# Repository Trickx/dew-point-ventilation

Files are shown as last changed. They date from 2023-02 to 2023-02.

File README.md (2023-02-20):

***

# Dew Point Ventilation

**Ventilation is the best and cheapest measure against damp cellars - at least if done right.
In this project, an ESP8266 (NodeMCU) monitors dew points from the inside and outside and activates up to 4 fans to transport the moisture in the air to the outside.**

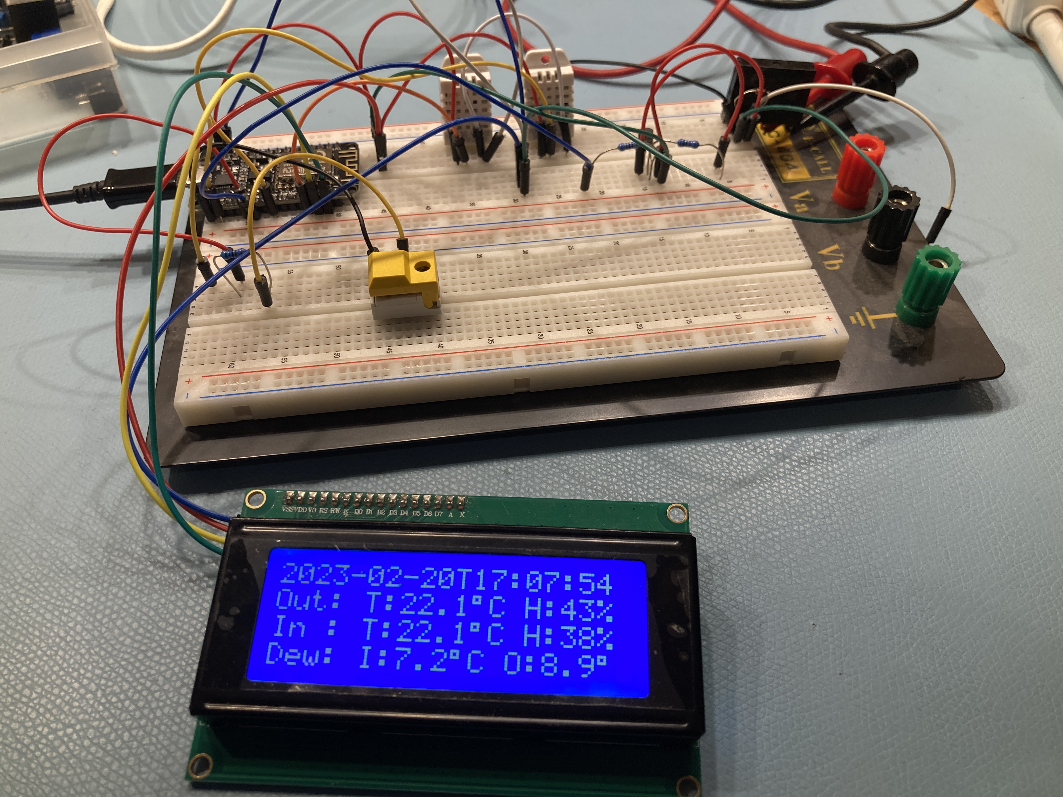
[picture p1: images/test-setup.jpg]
Test Setup


This project is inspired by 2 articles by the German Make magazine: [Taupunktlüfter](https://github.com/MakeMagazinDE/Taupunktluefter) and [Zirkulationspumpensteuerung](https://github.com/MakeMagazinDE/Zirkulationspumpensteuerung)
Instead of their Arduino approach, this projects makes use of ESP8266 and [Tasmota](https://github.com/arendst/Tasmota).

**Note: I don't take over any risk, nor responsibility for anything. If you decide to reproduce this project you will be killed by hardware or software.**

A PCB was designed with Autodesk's Eagle. The PCB is currently under test, so be aware.

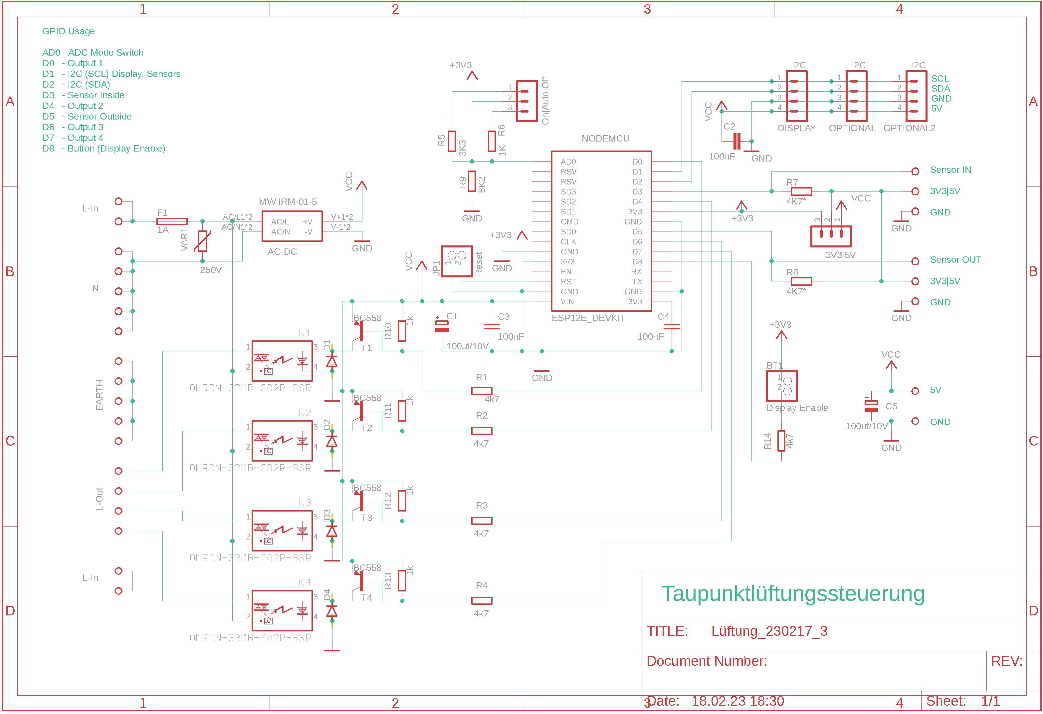
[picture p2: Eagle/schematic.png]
Schematic


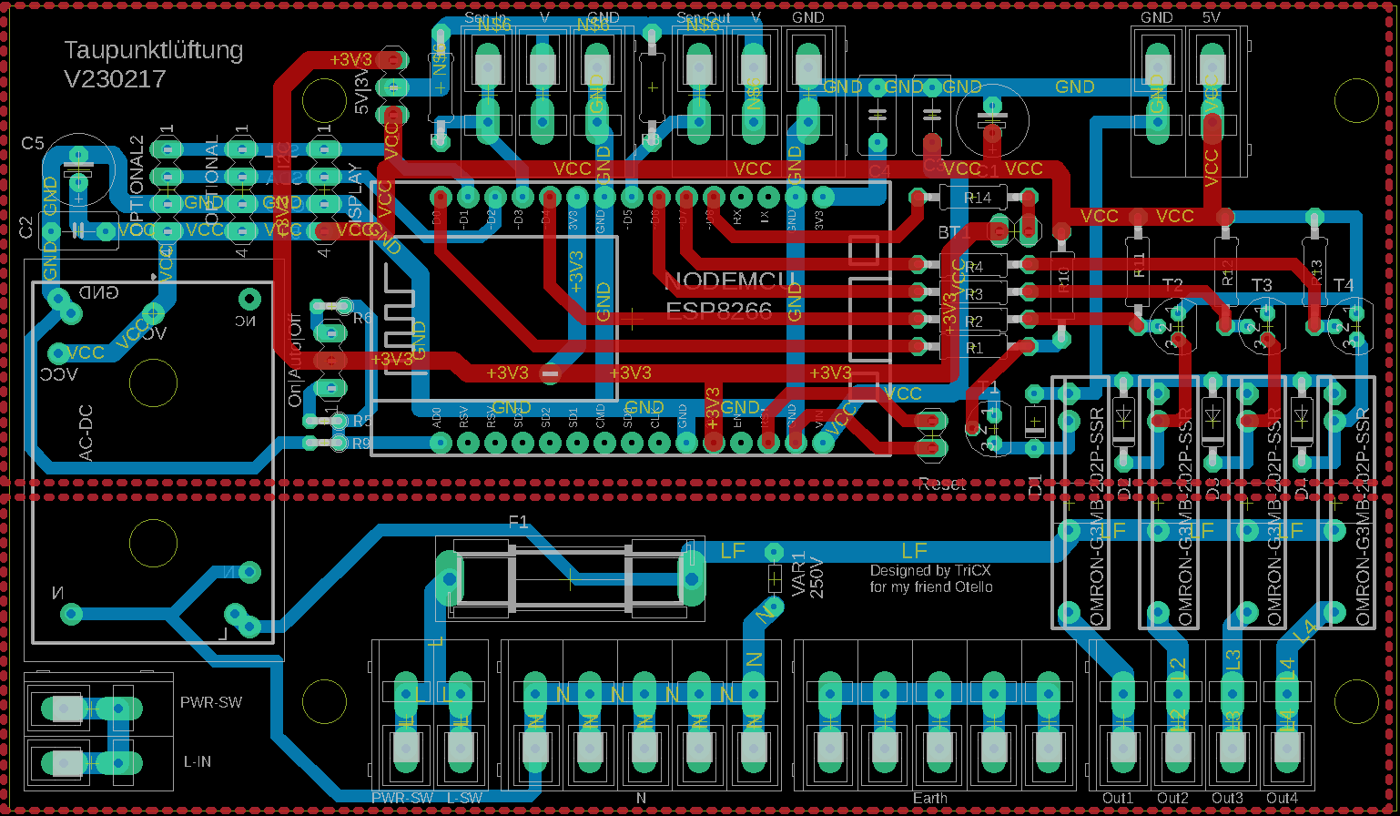
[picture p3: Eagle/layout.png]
Layout


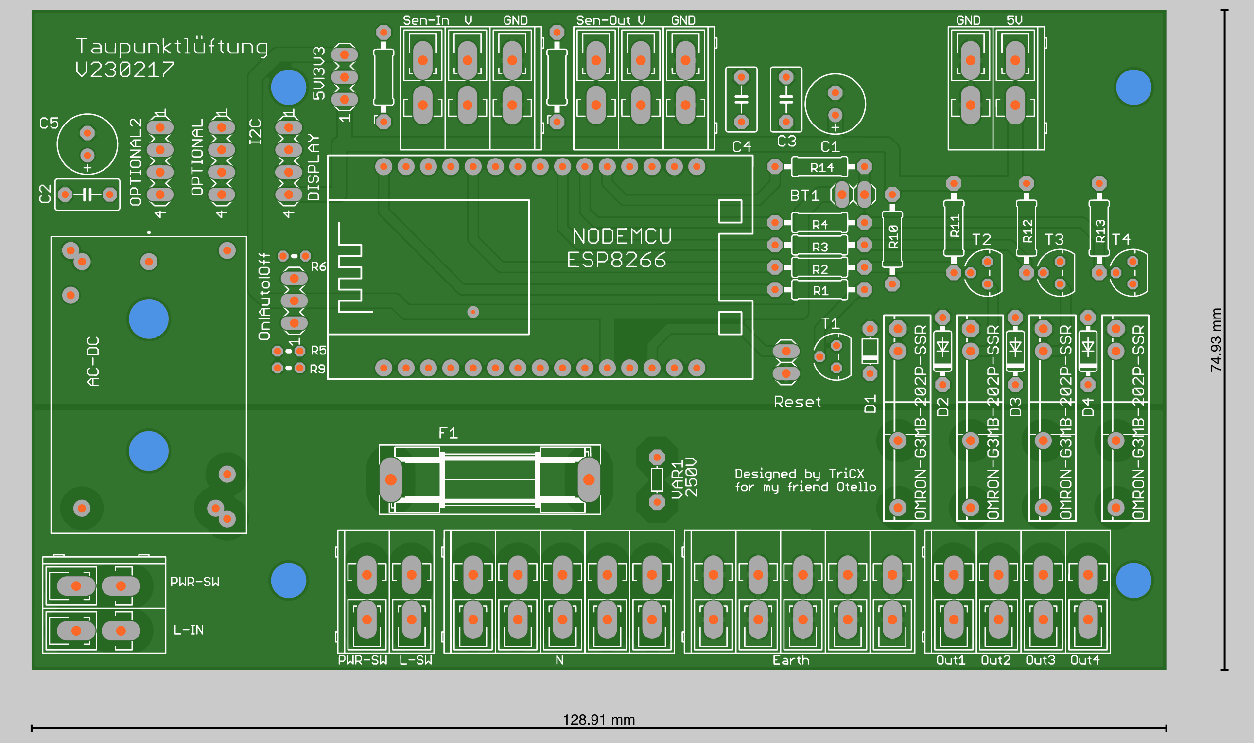
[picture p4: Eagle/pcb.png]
PCB


**Diffs from original designs by Make:**
- NodeMCUs instead of Arduino
- Tasmota and Script instead of Arduino coding
- 4 Outputs via solid state relais
- Multiple Sensor options:
- 1Wire
- I2C
- AM230x

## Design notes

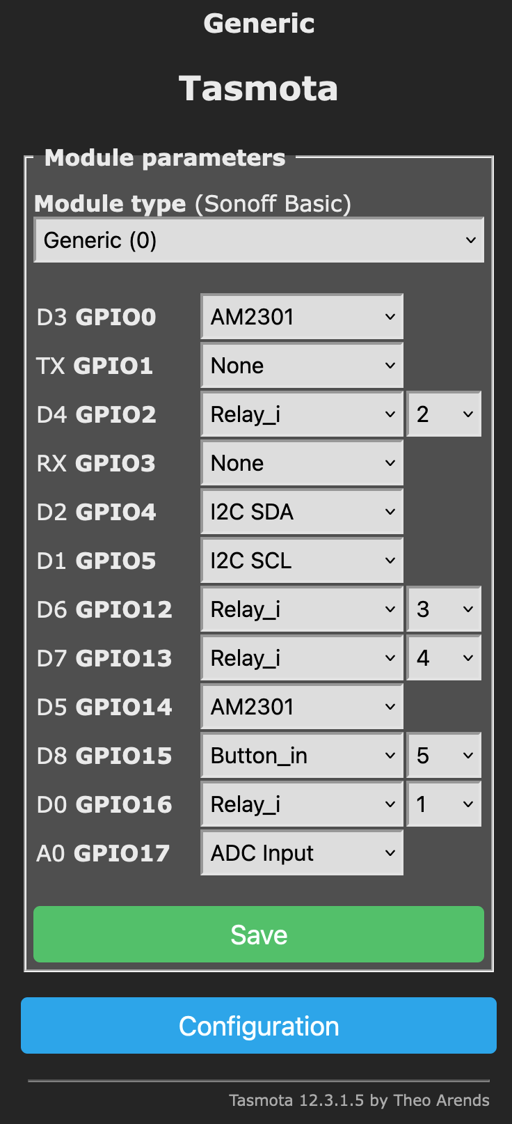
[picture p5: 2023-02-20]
Tasmota/configuration.png

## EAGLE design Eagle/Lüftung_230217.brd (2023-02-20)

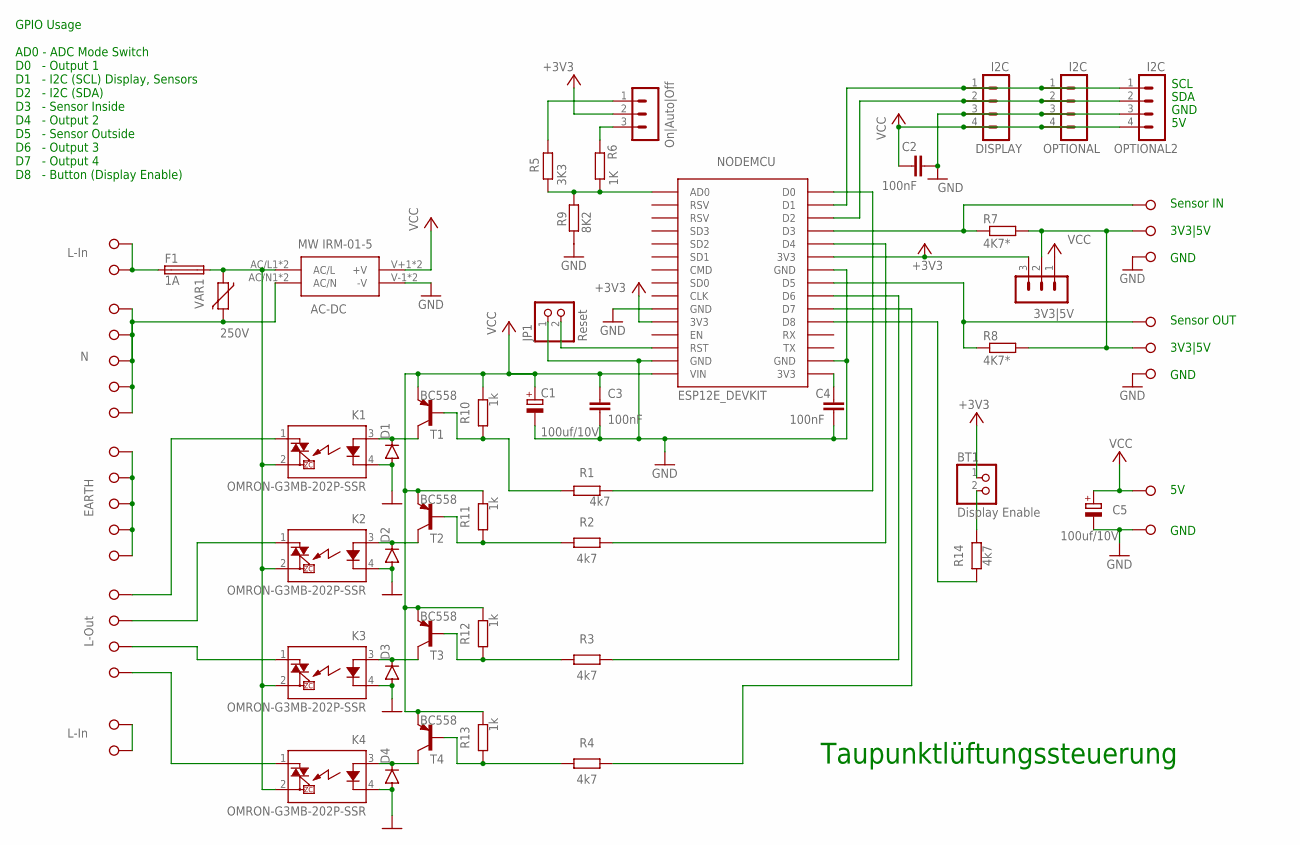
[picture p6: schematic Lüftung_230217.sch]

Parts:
5V|3V3: 3V3|5V; LüFTUNG_230217_2_CON-LSTB_MA03-1
AC-DC: MW IRM-01-5; LüFTUNG_230217_2_SAMACSYS_PARTS_IRM015
BT1: Display Enable; LüFTUNG_230217_2_PINHEAD_1X02
C1, C5: 100uf/10V; LüFTUNG_230217_2_MY_RCL_E2,5-7
C2, C3, C4: 100nF; LüFTUNG_230217_2_CAPACITOR-WIMA_C5B3.5
D1: LüFTUNG_230217_2_DIODE_1N4148; LüFTUNG_230217_2_DIODE_D-5
D2, D3, D4: LüFTUNG_230217_2_DIODE_1N4148DO35-7; LüFTUNG_230217_2_DIODE_DO35-7
DISPLAY: I2C; LüFTUNG_230217_2_CON-LSTB_MA04-1
F1: 1A; LüFTUNG_230217_2_MY_FUSE_SH22,5
JP1: Reset; LüFTUNG_230217_2_PINHEAD_1X02
K1, K2, K3, K4: OMRON-G3MB-202P-SSR; LüFTUNG_230217_2_OMRON-G3MB-202P-SSR_OMRON-G3MB-202P-SSR
NODEMCU: ESP12E_DEVKIT; LüFTUNG_230217_2_ESP12E_DEVKIT_ESP12E_DEVKIT
OPTIONAL, OPTIONAL2: I2C; LüFTUNG_230217_2_CON-LSTB_MA04-1
R1, R2, R3, R4, R14: 4k7; LüFTUNG_230217_2_MY_RCL_0207/10
R5: 3K3; LüFTUNG_230217_2_MY_RCL_0204V
R6: 1K; LüFTUNG_230217_2_MY_RCL_0204V
R7, R8: 4K7*; LüFTUNG_230217_2_MY_RCL_0207/10
R9: 8K2; LüFTUNG_230217_2_MY_RCL_0204V
R10, R11, R12, R13: 1k; LüFTUNG_230217_2_MY_RCL_0207/10
SWITCH: On|Auto|Off; LüFTUNG_230217_2_CON-LSTB_MA03-1
T1, T2, T3, T4: BC558; LüFTUNG_230217_2_TRANSISTOR-NEU-TO92_TO92
VAR1: 250V; LüFTUNG_230217_2_MY_VARISTOR_R-5
X1, X18: L-In; CON-WAGO-508_W236-1
X2, X17: L-In; CON-WAGO-508_W236-NOCAP
X3: N; CON-WAGO-508_W236-1
X4, X5, X6, X7: N; CON-WAGO-508_W236-NOCAP
X8: EARTH; CON-WAGO-508_W236-1
X9, X10, X11, X12: EARTH; CON-WAGO-508_W236-NOCAP
X13: L-Out; CON-WAGO-508_W236-1
X14, X15, X16: L-Out; CON-WAGO-508_W236-NOCAP
X19: Sensor-In; CON-WAGO-508_W236-NOCAP
X20, X23: 3V3; CON-WAGO-508_W236-NOCAP
X21, X24: GND; CON-WAGO-508_W236-1
X22: Sensor-Out; CON-WAGO-508_W236-NOCAP
X25: GND; CON-WAGO-508_W236-NOCAP
X26: VCC; CON-WAGO-508_W236-1

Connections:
230V-SWITCH: X17.1, X17.2, X18.1, X18.2
+3V3: 5V|3V3.3, BT1.1, NODEMCU.3V3@0 (3V3), NODEMCU.3V3@1 (3V3), SWITCH.2
EARTH: X8.1, X8.2, X9.1, X9.2, X10.1, X10.2, X11.1, X11.2, X12.1, X12.2
GND: AC-DC.V-1 (-V), AC-DC.V-2 (-V), C1.-, C2.2, C3.2, C4.2, C5.-, D1.A, D2.A, D3.A, D4.A, DISPLAY.3, JP1.1, K1.4 (K), K2.4 (K), K3.4 (K), K4.4 (K), NODEMCU.GND@0 (GND), NODEMCU.GND@1 (GND), NODEMCU.GND@2 (GND), NODEMCU.GND@3 (GND), OPTIONAL.3, OPTIONAL2.3, R9.2, X21.1, X21.2, X24.1, X24.2, X25.1, X25.2
L: F1.1, X1.1, X1.2, X2.1, X2.2
L2: K2.1 (DS1), X14.1, X14.2
L3: K3.1 (DS1), X15.1, X15.2
L4: K4.1 (DS1), X16.1, X16.2
L-OUT: K1.1 (DS1), X13.1, X13.2
LF: AC-DC.AC/L1 (AC/L), AC-DC.AC/L2 (AC/L), F1.2, K1.2 (DS2), K2.2 (DS2), K3.2 (DS2), K4.2 (DS2), VAR1.1
N: AC-DC.AC/N1 (AC/N), AC-DC.AC/N2 (AC/N), VAR1.2, X3.1, X3.2, X4.1, X4.2, X5.1, X5.2, X6.1, X6.2, X7.1, X7.2
unnamed: DISPLAY.1, NODEMCU.D1, OPTIONAL.1, OPTIONAL2.1
unnamed: R1.2, R10.2, T1.2 (B)
unnamed: NODEMCU.D5, R8.1, X22.1, X22.2
unnamed: D1.C, K1.3 (A), T1.3 (C)
unnamed: NODEMCU.D0, R1.1
unnamed: 5V|3V3.2, R7.2, R8.2, X20.1, X20.2, X23.1, X23.2
unnamed: D4.C, K4.3 (A), T4.3 (C)
unnamed: D3.C, K3.3 (A), T3.3 (C)
unnamed: R6.2, SWITCH.3
unnamed: D2.C, K2.3 (A), T2.3 (C)
unnamed: NODEMCU.D4, R2.1
unnamed: NODEMCU.D6, R3.1
unnamed: NODEMCU.D7, R4.1
unnamed: DISPLAY.2, NODEMCU.D2, OPTIONAL.2, OPTIONAL2.2
unnamed: NODEMCU.AD0, R5.1, R6.1, R9.1
unnamed: R5.2, SWITCH.1
unnamed: C4.1, NODEMCU.3V3@2 (3V3)
unnamed: R2.2, R11.2, T2.2 (B)
unnamed: R3.2, R12.2, T3.2 (B)
unnamed: R4.2, R13.2, T4.2 (B)
unnamed: BT1.2, R14.1
unnamed: NODEMCU.D8, R14.2
RST: JP1.2, NODEMCU.RST
SENS_IN: NODEMCU.D3, R7.1, X19.1, X19.2
VCC: 5V|3V3.1, AC-DC.V+1 (+V), AC-DC.V+2 (+V), C1.+, C2.1, C3.1, C5.+, DISPLAY.4, NODEMCU.VIN, OPTIONAL.4, OPTIONAL2.4, R10.1, R11.1, R12.1, R13.1, T1.1 (E), T2.1 (E), T3.1 (E), T4.1 (E), X26.1, X26.2

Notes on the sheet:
Taupunktlüftungssteuerung
Sensor IN 3V3|5V GND
5V GND
Sensor OUT 3V3|5V GND
SCL
SDA
GND
GPIO Usage AD0 - ADC Mode Switch D0 - Output 1 D1 - I2C (SCL) Display, Sensors D2 - I2C (SDA) D3 - Sensor Inside D4 - Output 2 D5 - Sensor Outside D6 - Output 3 D7 - Output 4 D8 - Button (Display Enable)

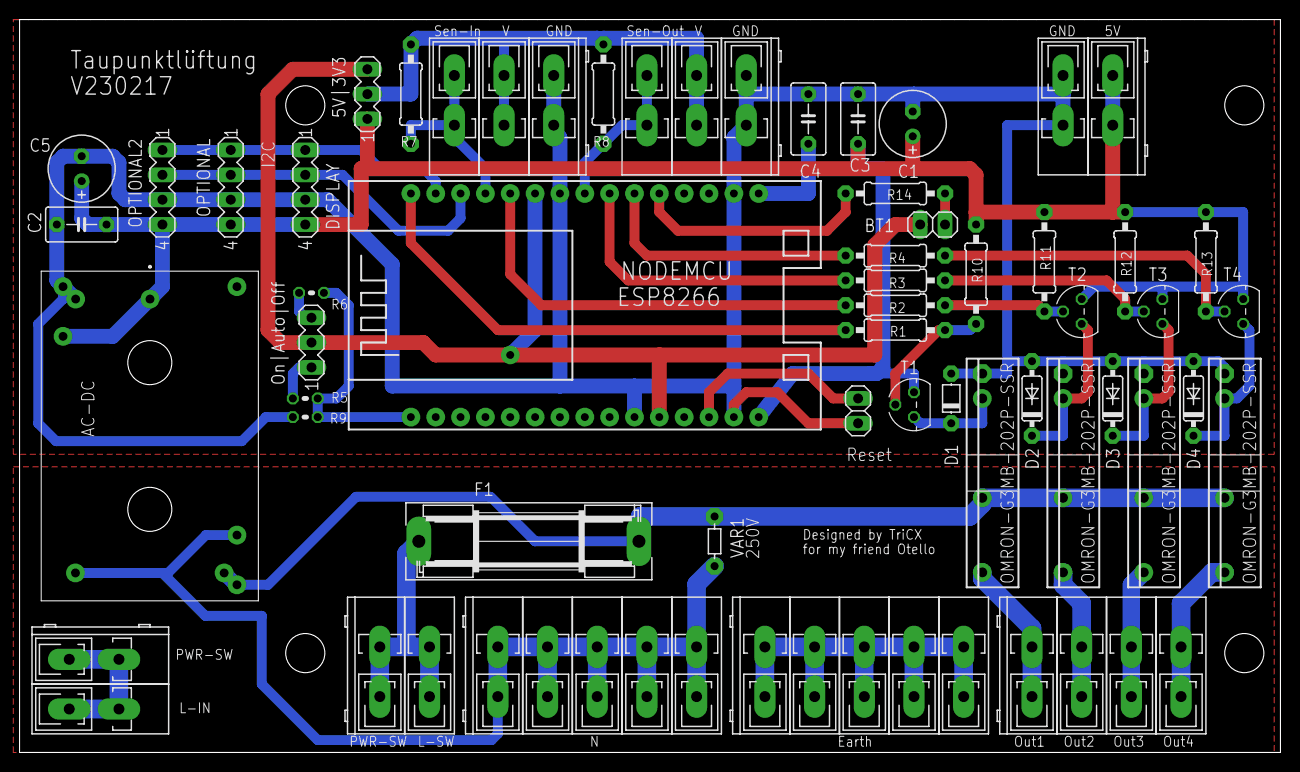
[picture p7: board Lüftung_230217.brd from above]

Board: 2 copper layers, 128.9 x 74.9 mm, 68 parts (0 on the bottom side), 36 nets.
